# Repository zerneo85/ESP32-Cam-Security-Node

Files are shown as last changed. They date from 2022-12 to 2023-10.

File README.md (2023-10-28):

# ESP32-Cam-Security-Node Project
ESP32-Cam Security Node managed bij Home Assistant with ESPHome

# Introduction
As with many of the projects we start, this one started simple and with a single purpose but quickly grew to what it is today. Current day, it’s one of the many devices i have build and configured in Home Assistant that has a crucial role in the area of security. It is build on ESP32-Cam combined with 2 motion detection sensors, 1 temperature sensor and a buzzer for audio notifications.

Besides the use of security (Cam & Motion detection) it also services roles in light control and doorbel control. I have created a couple of security display nodes (Security- Clock, Security-Cat) that show by using RGB Led and audio notification triggers of the security nodes. If there is enough intrest, i will document these projects as well.

# Continuous improvement
As my partner often points out i have a issue with trying to improve everything.
So if you have any suggestions or improvements i would be very happy to implement them! While writing this i realizes i could add a RGB Led and i will try to implement this short term. I would be very happy if someone could help with the RCWL-0516 because it is still giving false triggers……

# Sensors & Components
I have used the sensors below in the project. I don’t have positive experience with the HC-SR501 and was unable to fix all the false triggers it gives.
The STL files allow use of DHT11 or ds18b20, i think the DHT11 has better accuracy.
- ESP32Cam -Microcontroller
- AM312 – PIR Sensor
- * HC-SR501 -PIR Sensor (I was not able to fix the huge amount of false triggers)
- Micro USB 5V DIP Adapter board – Power
- Passive piezo buzzer
- Dallas ds18b20 – Temperature Sensor
- Resistor R4,7K
- DHT11 – Temperature Sensor
- RCWL-0516 – Doppler Sensor

# PCB Design
The PCB i used is a PCB Board Hole Grid Board from 7cm x 3cm that i soldered the sensors on. All the sensors (ESP32 Cam & PIR) that are on the front of the PCB are detachable, to achieve this i soldered 2 rows of 8 female pins en for the PIR sensor a 3 row female pin.

For power & ground i sewed a wire on row 3 & 8 over the lengt of the PCB.
The micro USB DIP i soldered on A4 for ground (i connected it to row 3) and A8 for 5v power.

## PCB Front
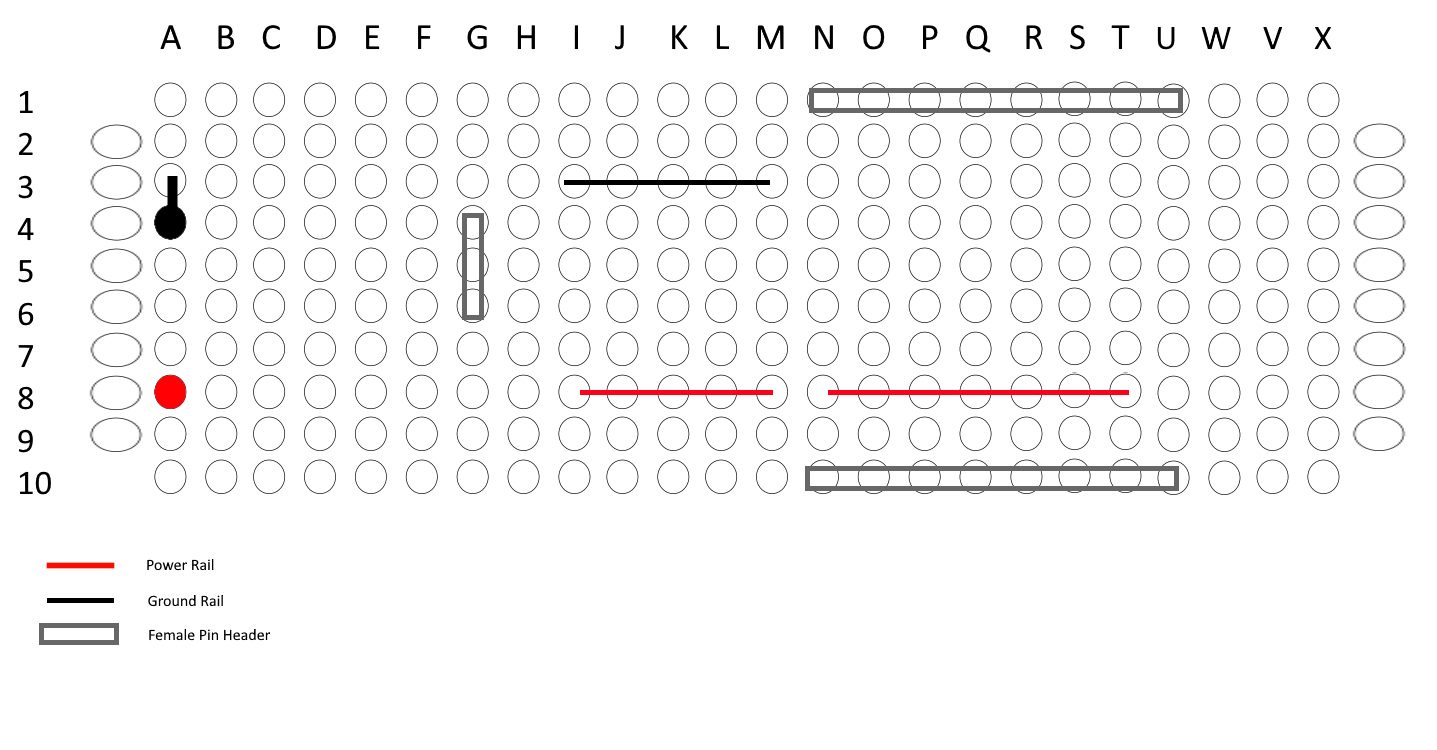
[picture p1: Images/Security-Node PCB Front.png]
PCB Front


## PCB Back
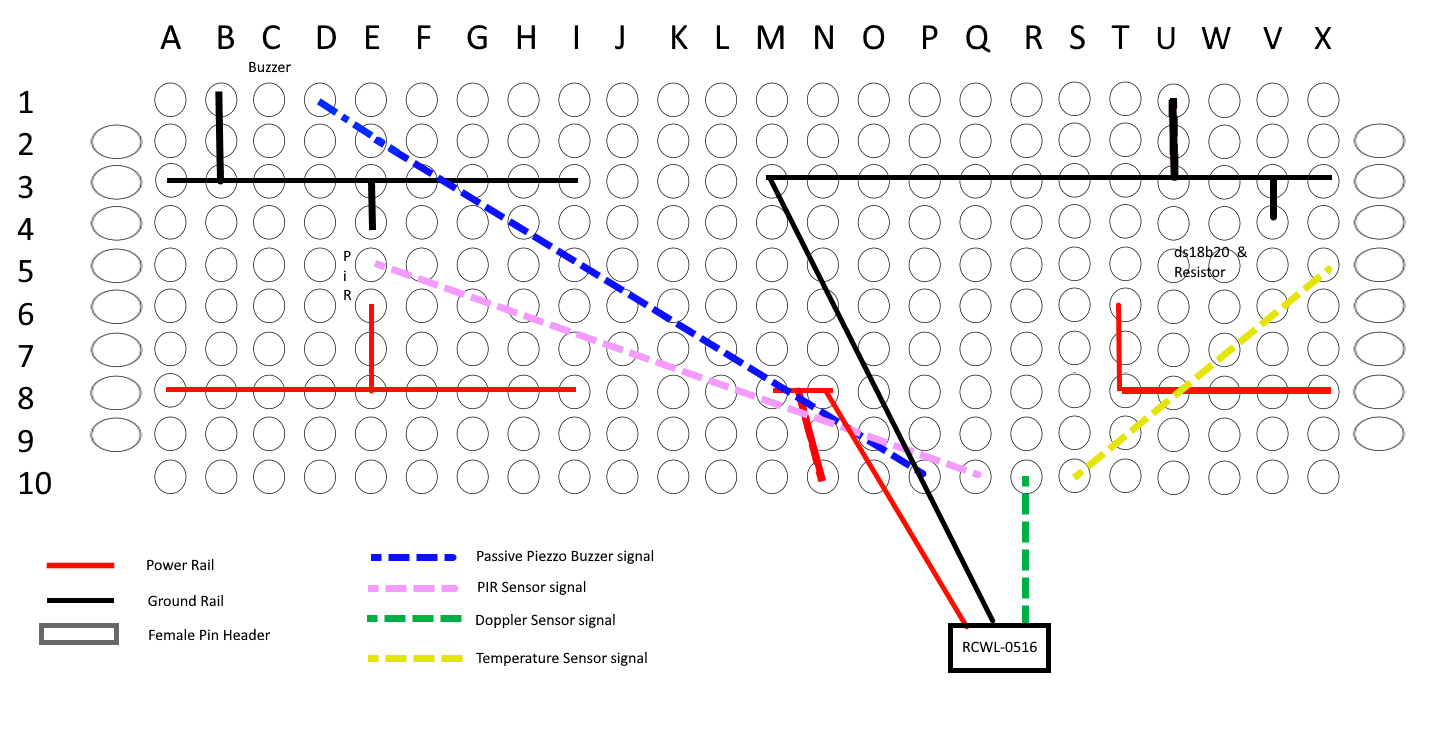
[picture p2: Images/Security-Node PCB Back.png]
PCB Back


# ESP Home YAML file for Home Assistant
In the directory [Code](https://github.com/zerneo85/ESP32-Cam-Security-Node/tree/main/Code) you can find the YAML file that i made and use in ESP Home in Home Assistant. Some important points are:

- I use the secrets file in ESP Home for all sensitive or device related data.
- The file makes use of the ds18b20 temperature sensor and not the DHT11 sensor.
- The ds18b20 has a disadvance in accuracy and requires a offset in temperature.
- To fix false alarms of the PIR & Doppler sensor i use a delayed_on value, for the PIR sensor it solves the false alarms.
- The Doppler sensor still requires some troubleshooting to get more stable.

```
esphome:
  name: livingroom-security-node
  platform: ESP32
  board: esp32cam

wifi:
  ssid: !secret wifi_ssid
  password: !secret wifi_password
  # Optional manual IP
  manual_ip:
    static_ip: !secret static_ip_livingroom-security-node
    gateway: !secret gateway
    subnet: !secret subnet
    dns1: !secret dns1

  # Enable fallback hotspot (captive portal) in case wifi connection fails
  ap:
    ssid: "Livingroom-Seurity-Node"
    password: !secret hotspot_livingroom-security-node

captive_portal:

# Enable logging
logger:
  level: INFO

# Enable Home Assistant API
ota:
  password: !secret ota_livingroom-security-node

# ESP32 Cam configuration entry
esp32_camera:
  external_clock:
    pin: GPIO0
    frequency: 20MHz
  i2c_pins:
    sda: GPIO26
    scl: GPIO27
  data_pins: [GPIO5, GPIO18, GPIO19, GPIO21, GPIO36, GPIO39, GPIO34, GPIO35]
  vsync_pin: GPIO25
  href_pin: GPIO23
  pixel_clock_pin: GPIO22
  power_down_pin: GPIO32
  vertical_flip: true
  resolution: 1280x1024
  jpeg_quality: 10
  
# Image settings
  name: Livingroom Camera

# Binary Sensors PIR & Doppler configuration entry
binary_sensor:
  - platform: gpio
    pin: GPIO13
    name: "Livingroom PIR Sensor"
    device_class: motion
    filters:
      - delayed_on: 3000ms    
  - platform: gpio
    pin: GPIO15
    name: "Livingroom Doppler Sensor"
    device_class: motion
    filters:
      - delayed_on: 3000ms

# Output ESP32 Cam light & Buzzer rtttl configuration entry
output:
  - platform: gpio
    pin: GPIO4
    id: gpio_4
  - platform: ledc
    pin: GPIO12
    id: rtttl_out
    channel: 2

light:
  - platform: binary
    output: gpio_4
    name: "Livingroom Camera Light"
    
rtttl:
  output: rtttl_out
  on_finished_playback:
    - logger.log: 'Song ended!'

api:
  services:
    - service: play_rtttl
      variables:
        song_str: string
      then:
        - rtttl.play:
            rtttl: !lambda 'return song_str;'

# Temperature configuration entry
dallas:
  - pin: GPIO14

sensor:
  - platform: dallas
    address: 0x5B3C01D6079A2228
    name: "Livingroom Temperature Sensor"
    filters:
      - offset: -9.6

```

# 3D Print STL files
I published the project on Thingiverse, https://www.thingiverse.com/thing:5064859

But the STL files can also be downloaded from the directory [Designs](https://github.com/zerneo85/ESP32-Cam-Security-Node/tree/main/Designs).

# Images – 3D print & Sensors & PCB
## Security-Node Front Closed
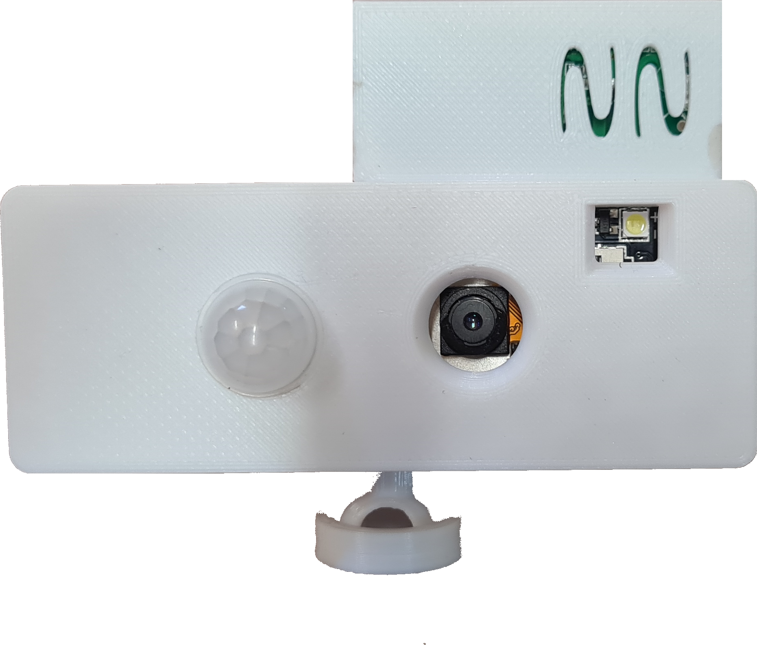
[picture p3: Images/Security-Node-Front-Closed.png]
PCB Front


## Security-Node Front Open
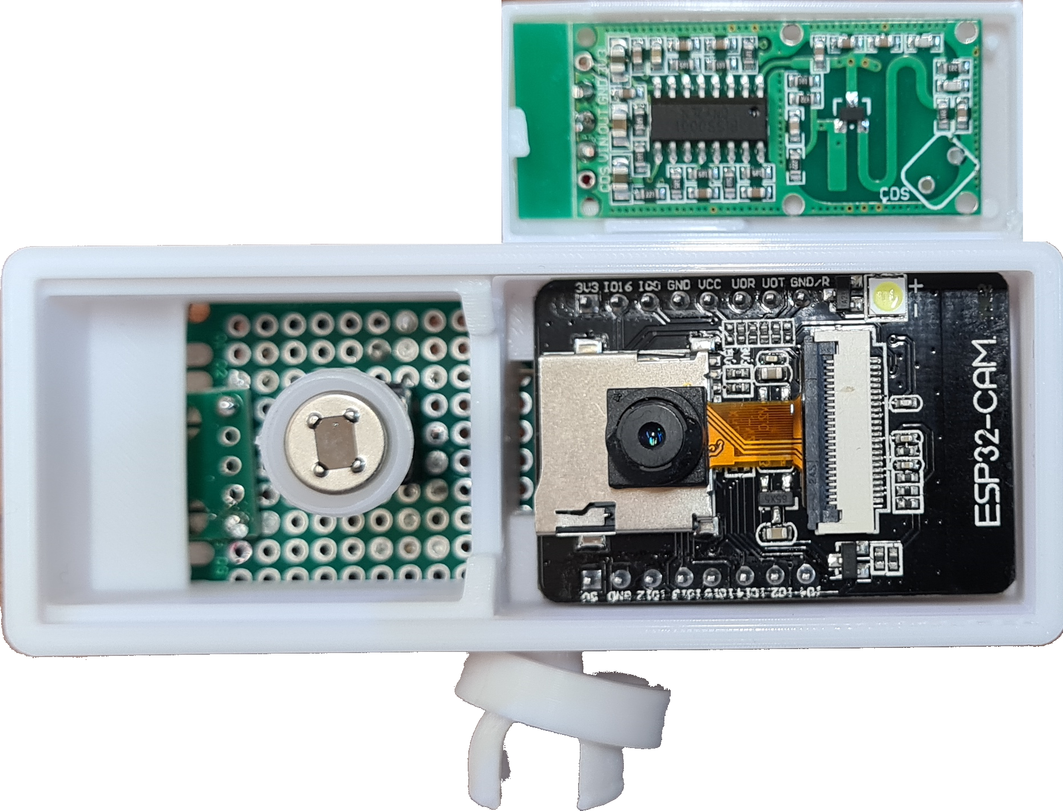
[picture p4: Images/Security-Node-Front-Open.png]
PCB Front


## Security-Node Back
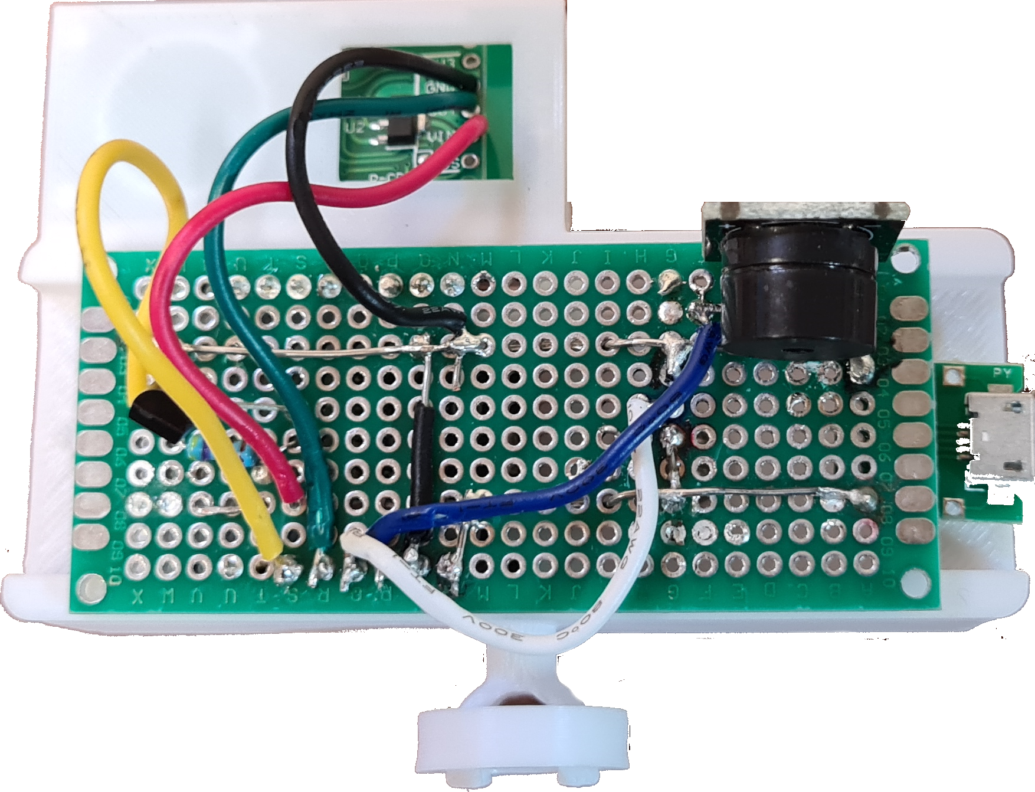
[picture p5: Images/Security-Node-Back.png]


# Images – STL Screenshots
## Security-Node body STL screenshot
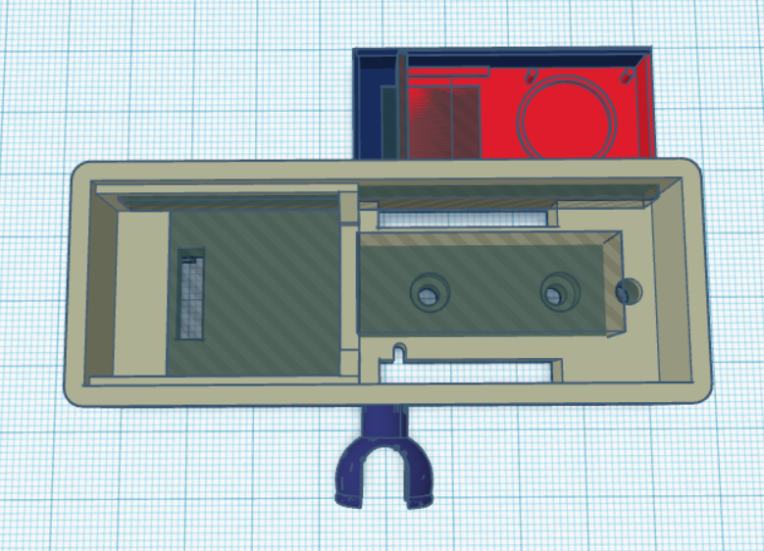
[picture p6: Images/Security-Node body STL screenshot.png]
Security-Node body STL screenshot


## Security-Node ESP32 Cam & AM312 Lid STL screenshot
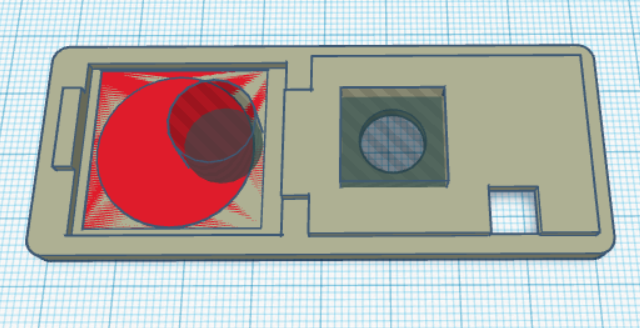
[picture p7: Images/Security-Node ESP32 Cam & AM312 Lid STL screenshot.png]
Security-Node ESP32 Cam & AM312 Lid STL screenshot


## Security-Node RCWL Doppler Lid STL screenshot
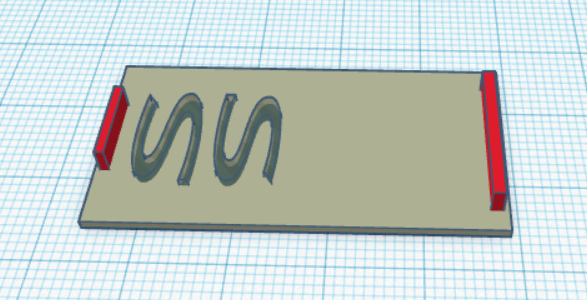
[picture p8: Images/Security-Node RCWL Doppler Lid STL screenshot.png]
Security-Node RCWL Doppler Lid STL screenshot


## Security-Node ESP32 Cam & HC-SR501 Lid STL screenshot
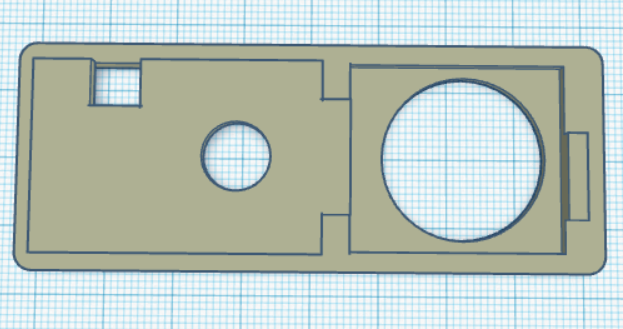
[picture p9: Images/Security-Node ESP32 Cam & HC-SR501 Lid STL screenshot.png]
Security-Node ESP32 Cam & HC-SR501 Lid STL screenshot


# Images – 3D print Pictures
## Security-Node Body Front
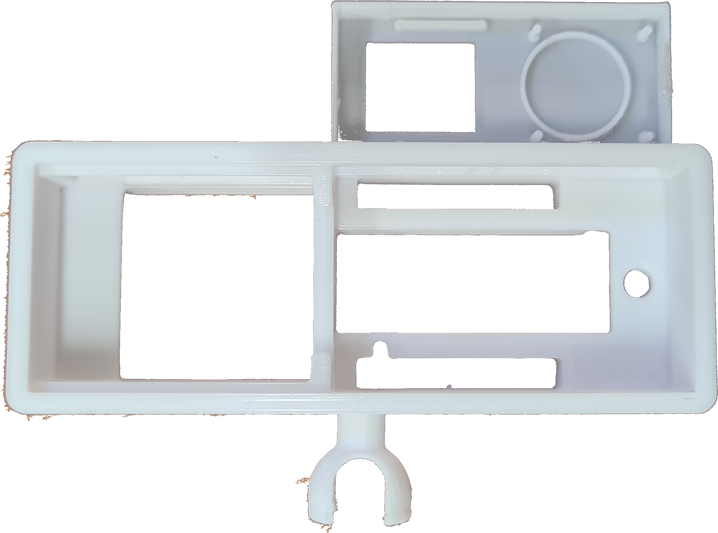
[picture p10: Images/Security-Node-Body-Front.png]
Security-Node Body Front


## Security-Node Body Back
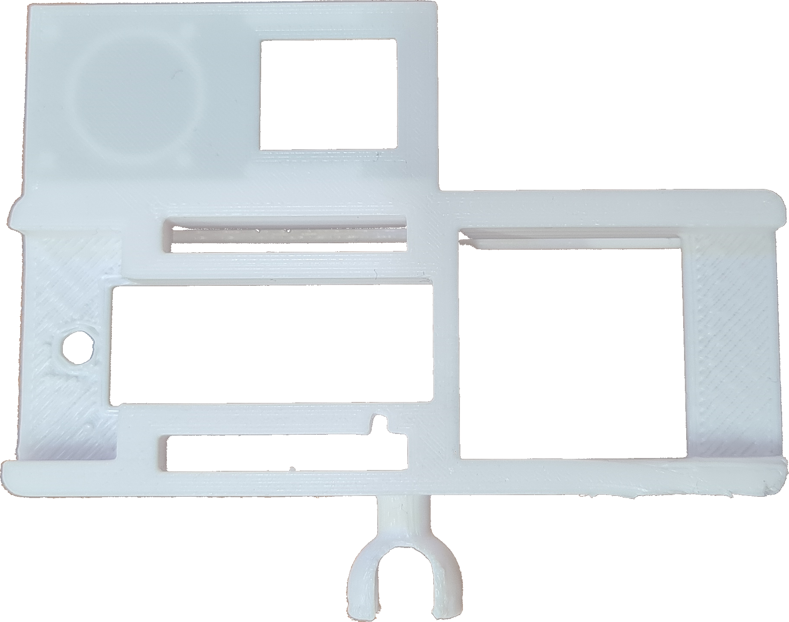
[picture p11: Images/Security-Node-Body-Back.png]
Security-Node Body Back


## Security-Node RCWL Doppler Lid
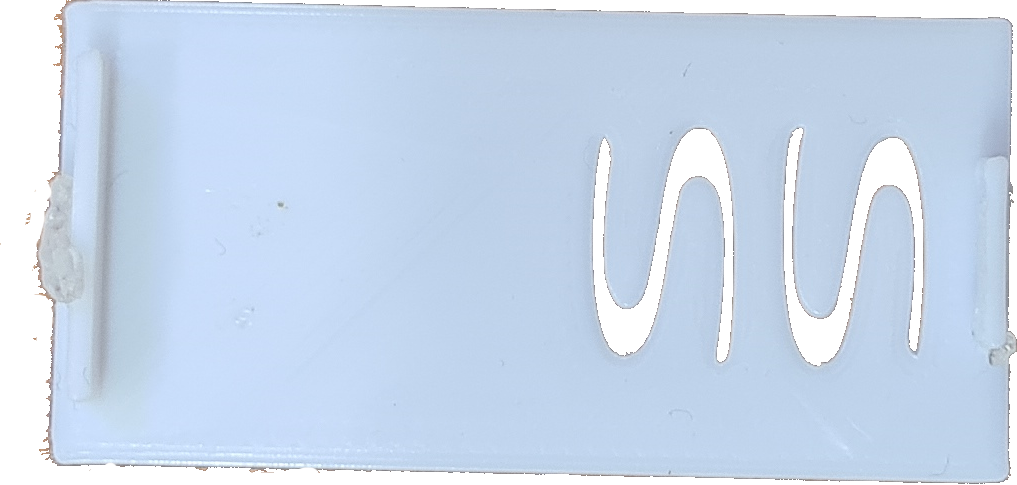
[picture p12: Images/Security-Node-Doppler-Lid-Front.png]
Security-Node RCWL Doppler Lid


## Security-Node ESP32 Cam & AM312 Lid
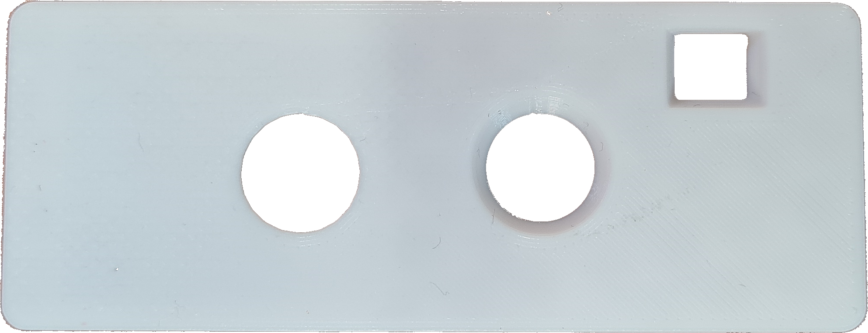
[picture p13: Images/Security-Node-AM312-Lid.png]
Security-Node ESP32 Cam & AM312 Lid


## Security-Node ESP32 Cam & HC-SR501 Lid
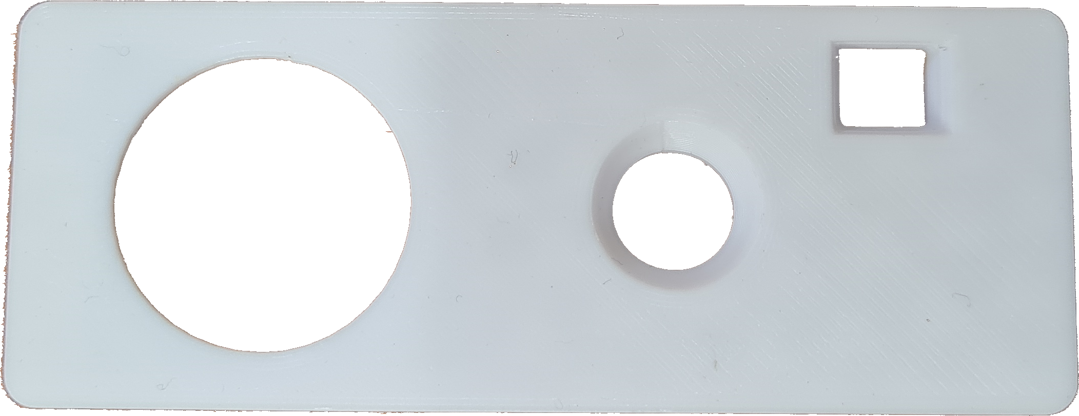
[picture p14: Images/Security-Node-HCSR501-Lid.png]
Security-Node ESP32 Cam & HC-SR501 Lid


# Images – Sensors & PCB
## PCB empty
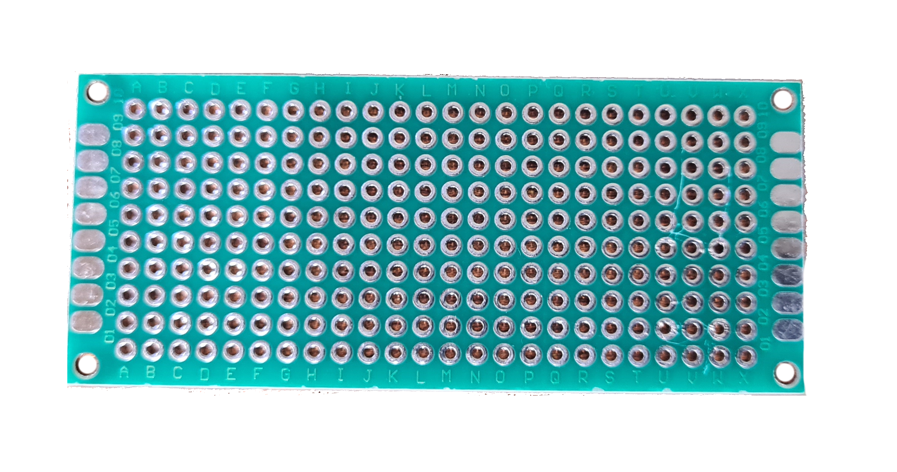
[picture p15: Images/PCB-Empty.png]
PCB Empty


## PCB Back
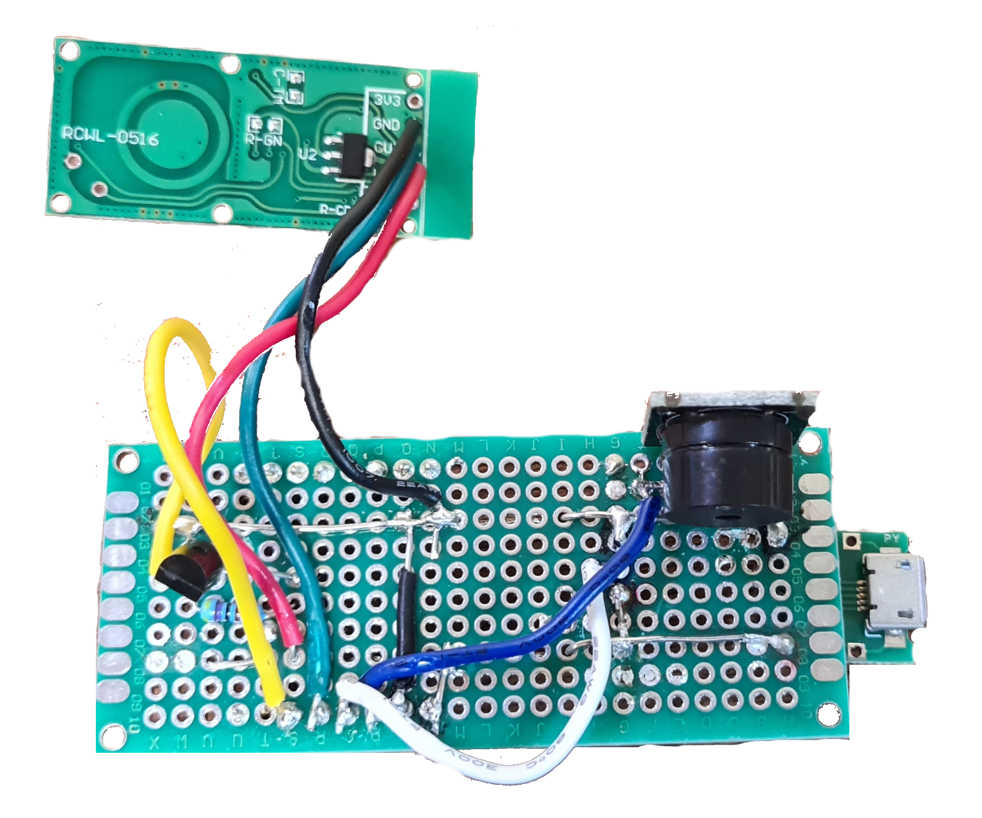
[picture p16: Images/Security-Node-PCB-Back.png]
PCB Back


## PCB Front
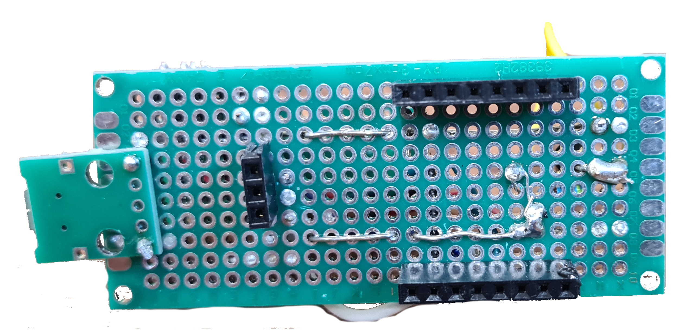
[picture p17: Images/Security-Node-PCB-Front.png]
PCB Front


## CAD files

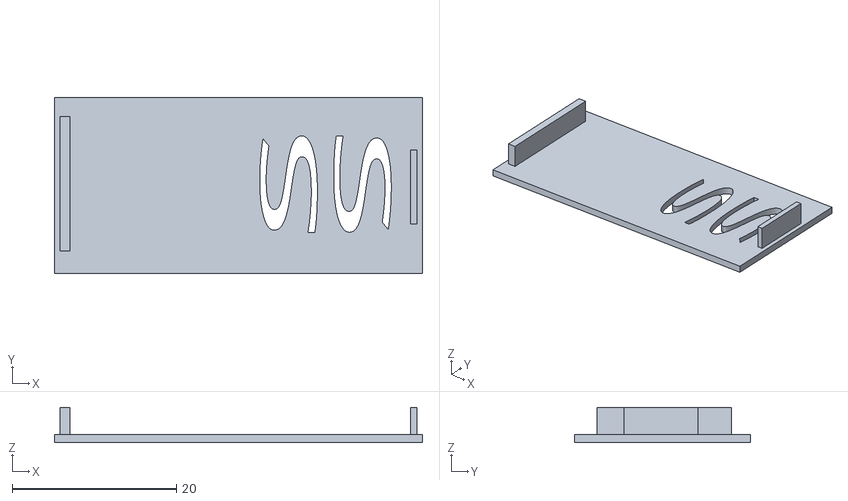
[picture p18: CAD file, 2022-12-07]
Designs/Security-node_Doppler_Lid.stl
44.8 x 21.4 x 4.30

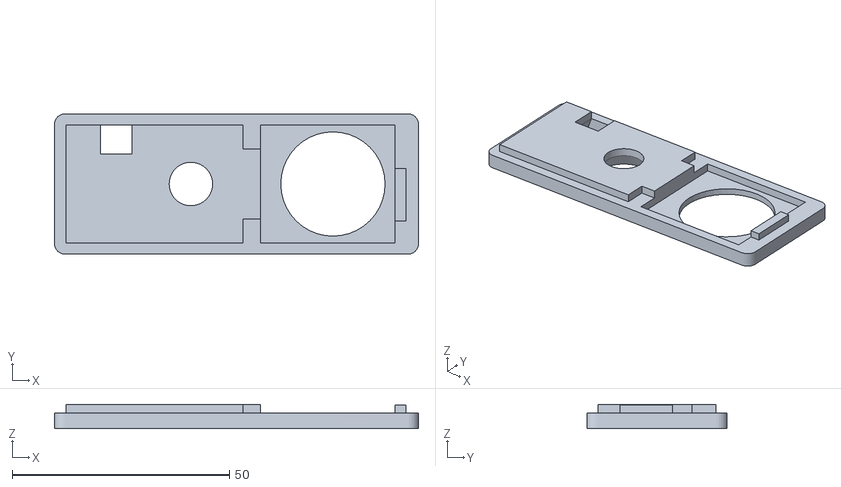
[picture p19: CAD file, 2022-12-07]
Designs/Security-node_ESP32Cam_HC-SR501_Lid.stl
83.8 x 32.3 x 5.60

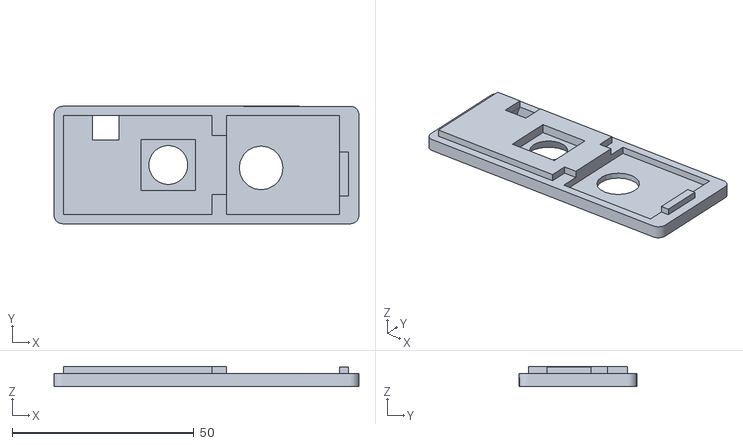
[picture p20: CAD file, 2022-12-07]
Designs/Security-node_ESP32Cam_AM312_Lid.stl
83.8 x 32.3 x 5.60

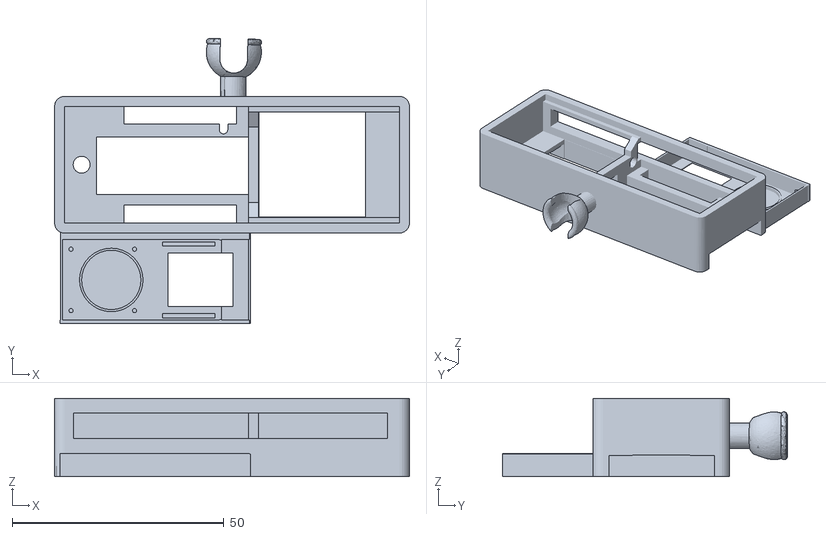
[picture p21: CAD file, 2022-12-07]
Designs/Security-node_Body.stl
83.8 x 67.3 x 18.5
